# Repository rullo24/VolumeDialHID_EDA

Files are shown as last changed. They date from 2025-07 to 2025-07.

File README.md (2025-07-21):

# Custom USB HID Volume Controller – KiCad Design
KiCad schematic and PCB layout for a USB HID volume controller based on the RP2040. Features rotary encoder for volume up, volume down, and play/pause, with USB-C and onboard voltage regulation.

## Features
- RP2040 microcontroller (QFN-56 package)
- USB-C with ESD protection and fuse
- Rotary encoder with pushbutton
- Status LEDs
- SWD and UART headers for debugging

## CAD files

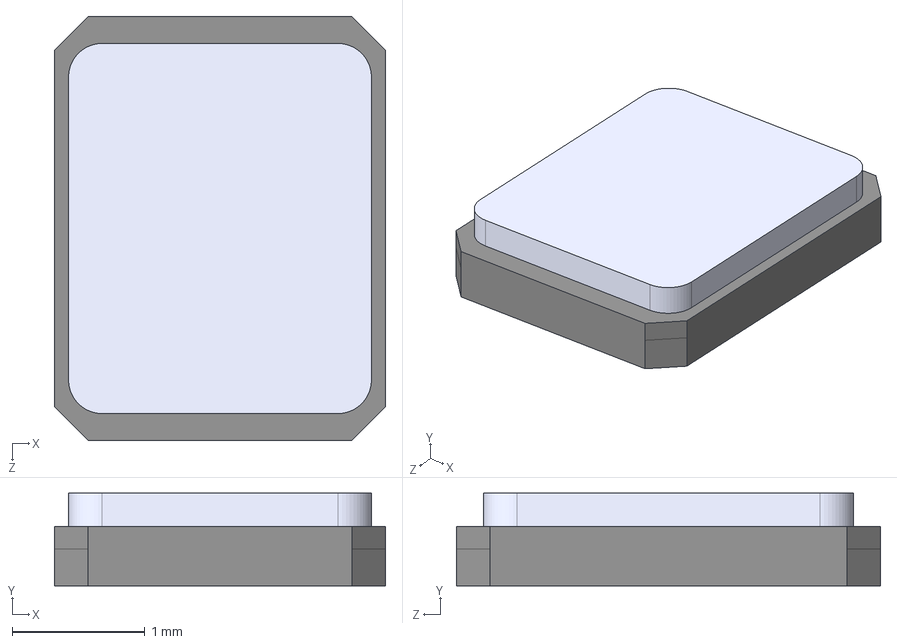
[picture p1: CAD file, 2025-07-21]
Ext_Symbols_and_Footprints/ABM8-272-T3/ABM8-272-T3.step
2.50 x 0.7 x 3.20 mm

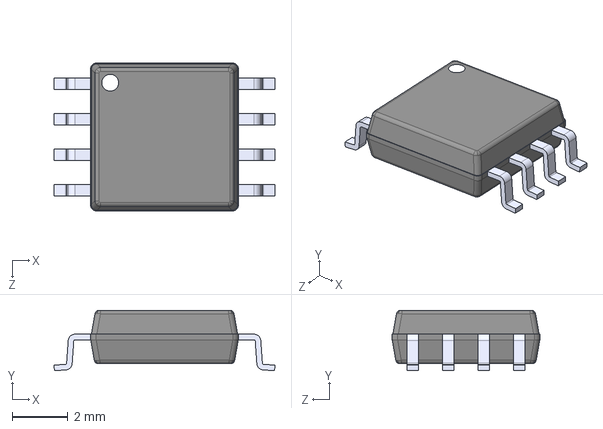
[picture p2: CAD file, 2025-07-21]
Ext_Symbols_and_Footprints/W25Q128JVSIQ/W25Q128JVSIQ.step
7.90 x 2.16 x 5.28 mm

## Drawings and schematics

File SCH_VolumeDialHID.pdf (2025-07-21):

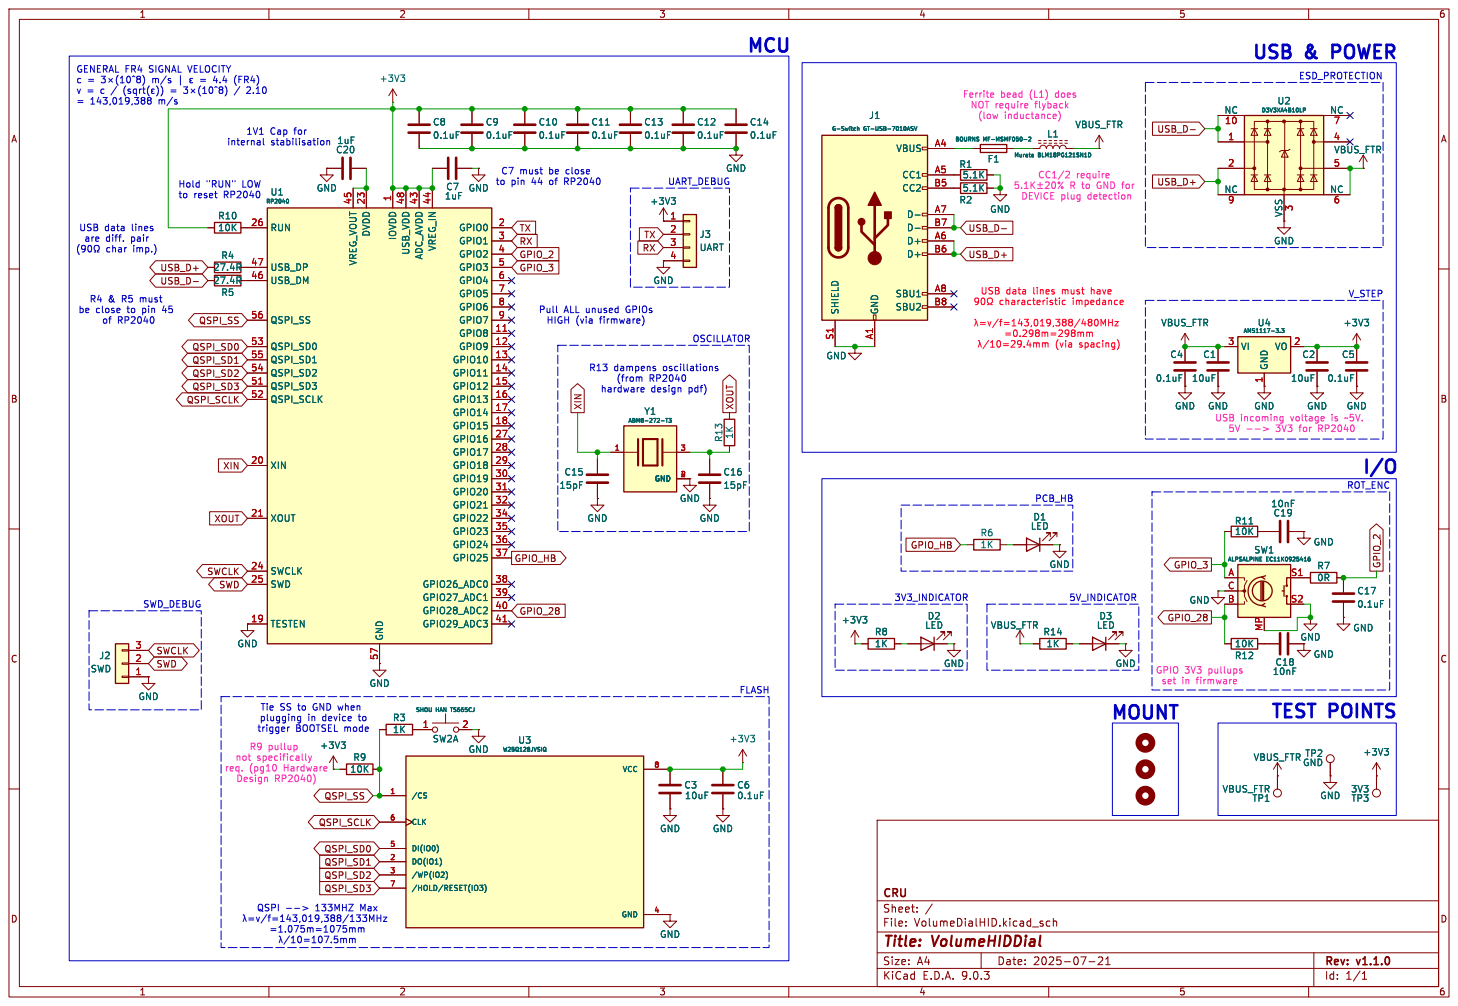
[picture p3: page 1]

þÿ5.1K±20%R to GND for DEVICE plug detection Ferrite bead (L1) does NOT require flyback

to reset RP2040 USB data lines are diff. pair

to pin 44 of RP2040 Pull ALL unused GPIOs HIGH (via firmware) Tie SS to GND when

USB data lines must have

R4 & R5 must be close to pin 45

hardware design pdf) R9 pullup

Id: 1/1 Title: VolumeHIDDial File: VolumeDialHID.kicad_sch Sheet: / CRU

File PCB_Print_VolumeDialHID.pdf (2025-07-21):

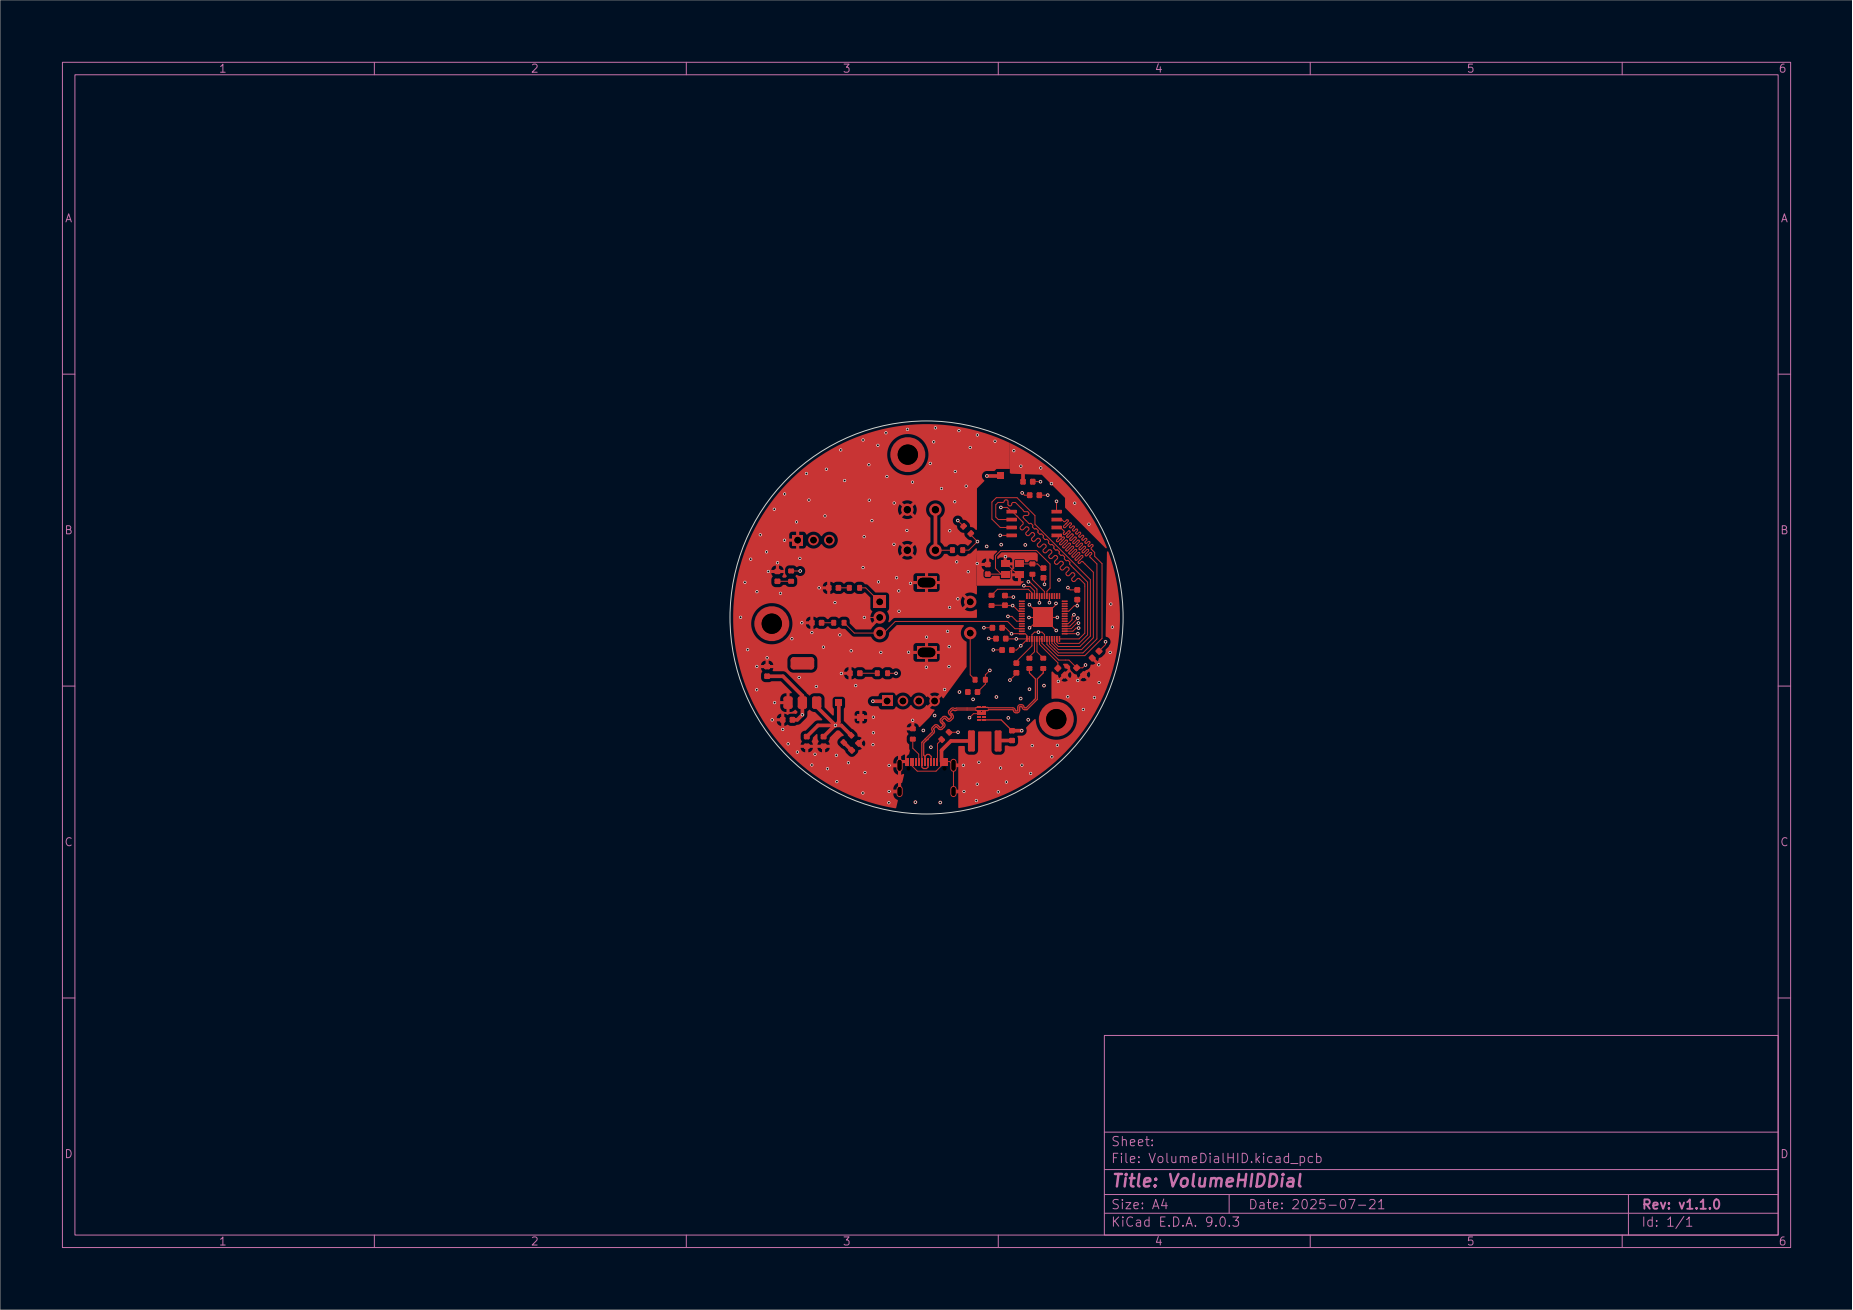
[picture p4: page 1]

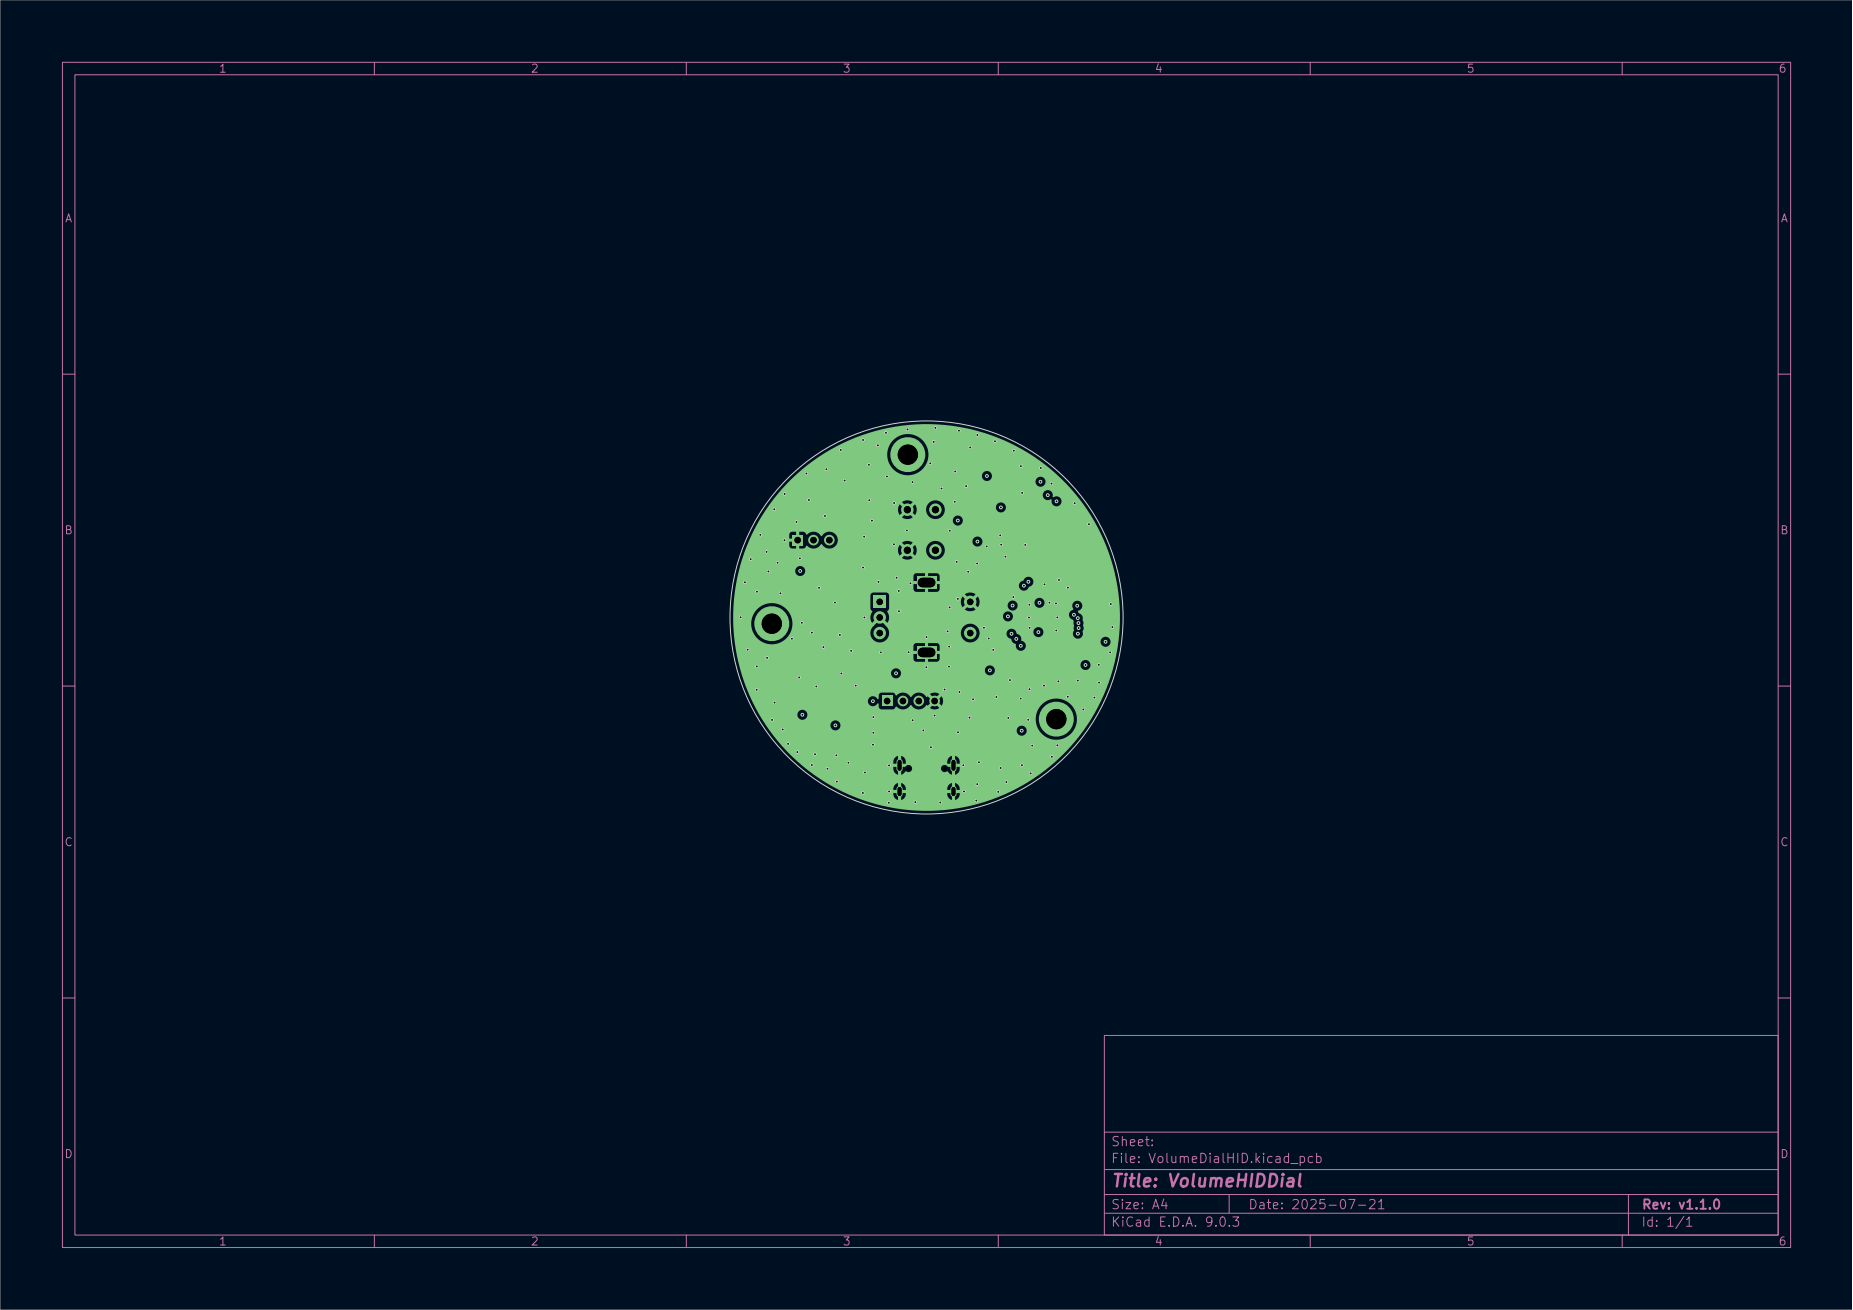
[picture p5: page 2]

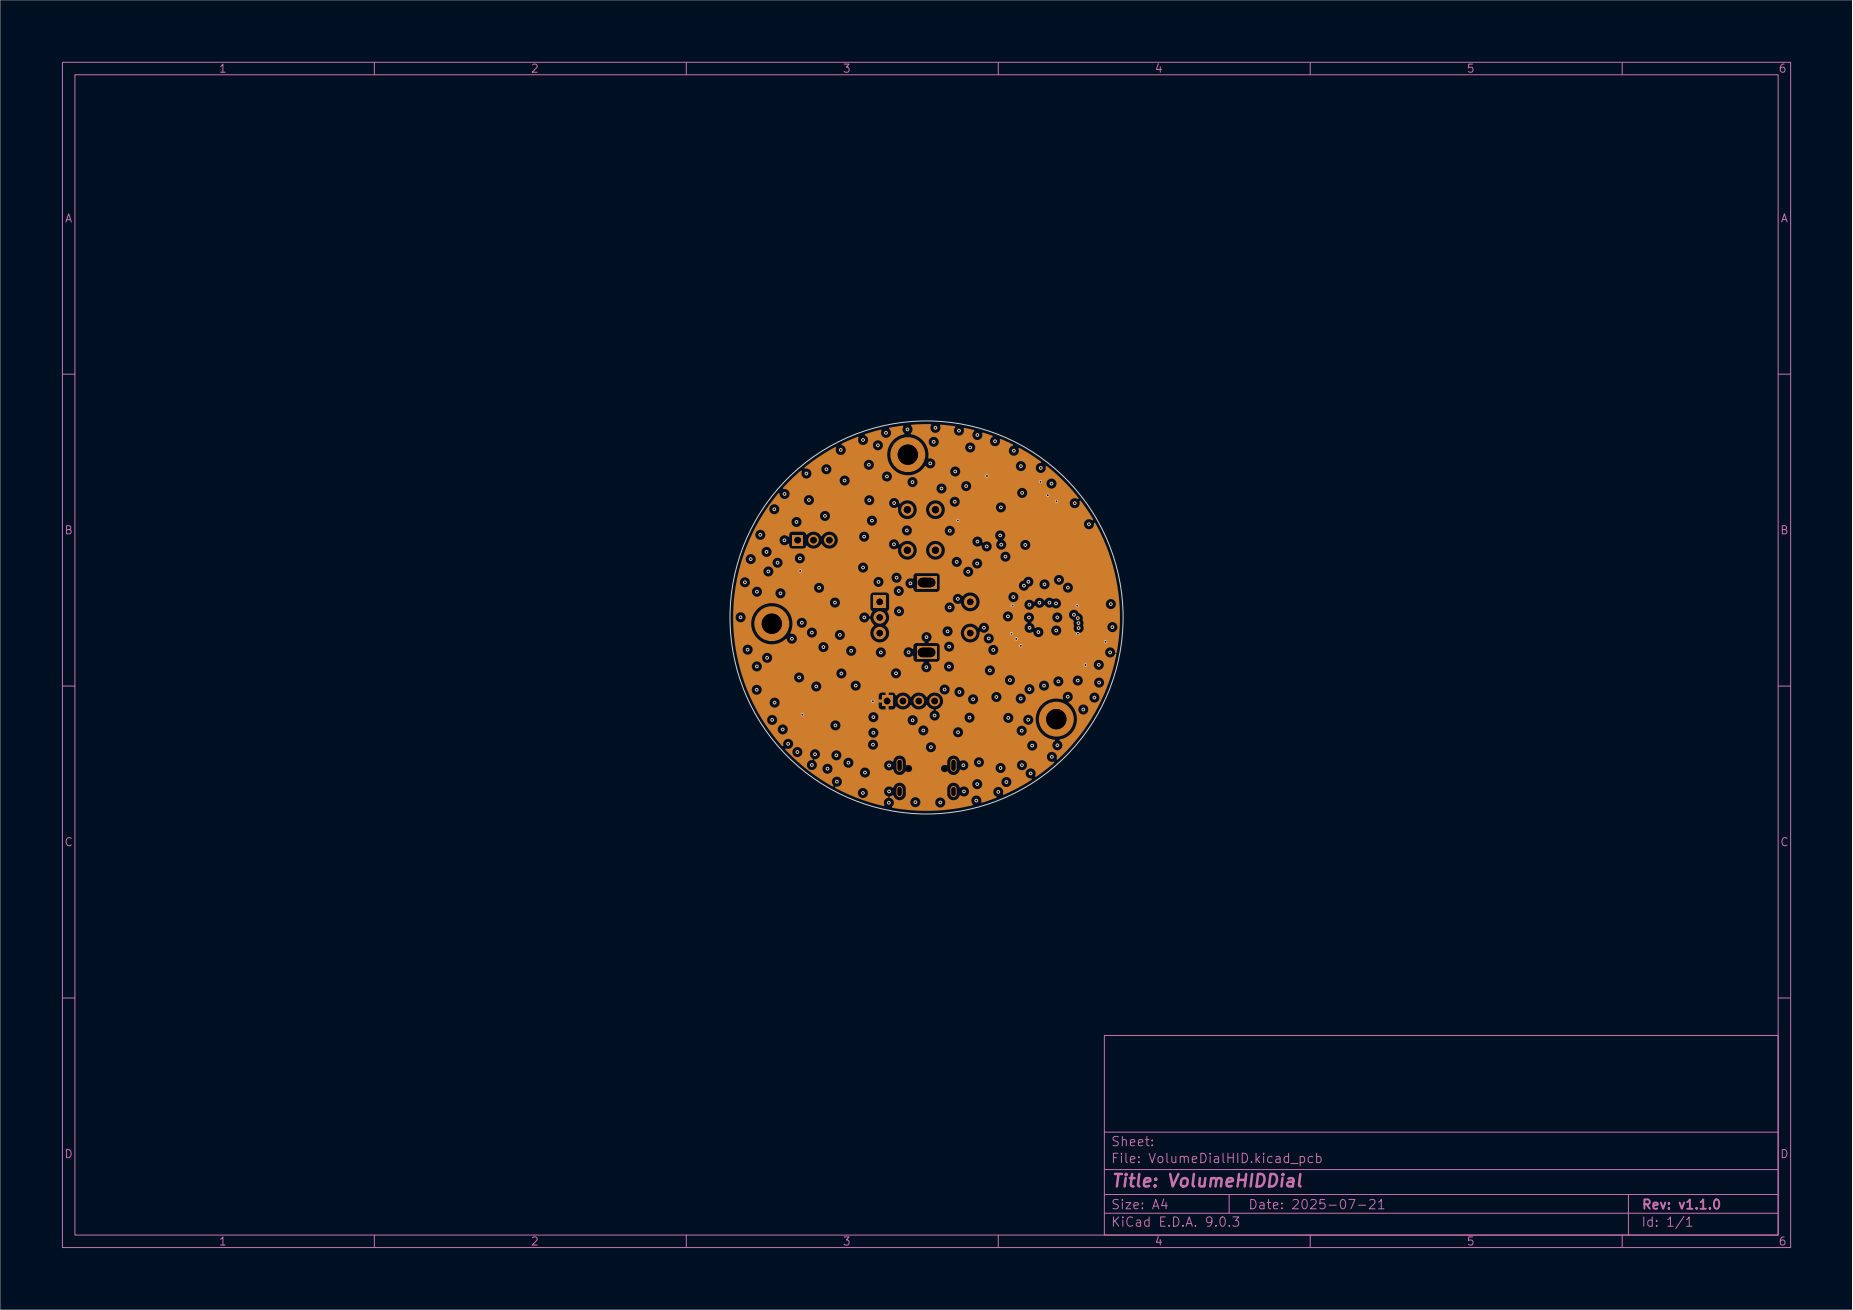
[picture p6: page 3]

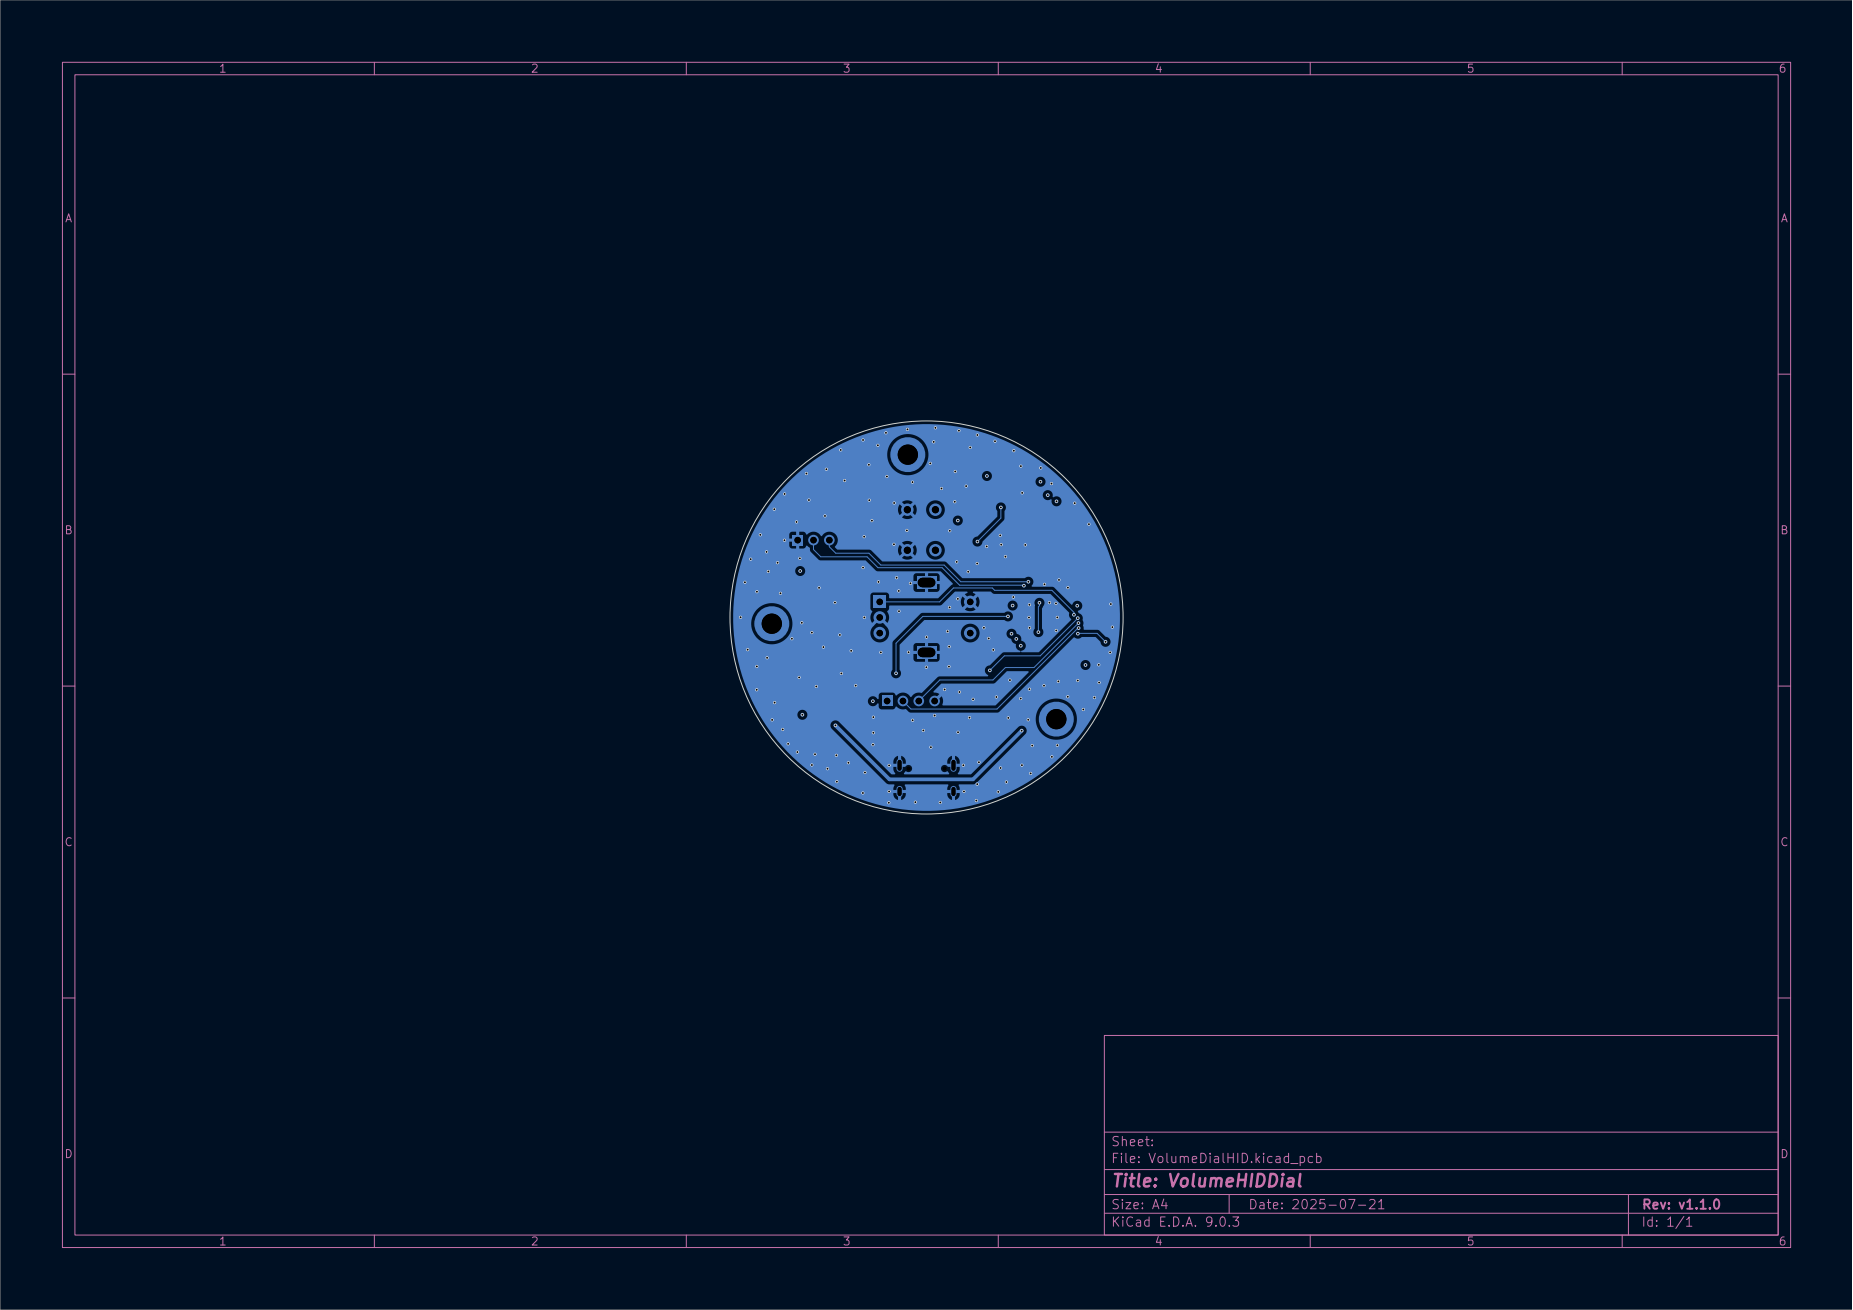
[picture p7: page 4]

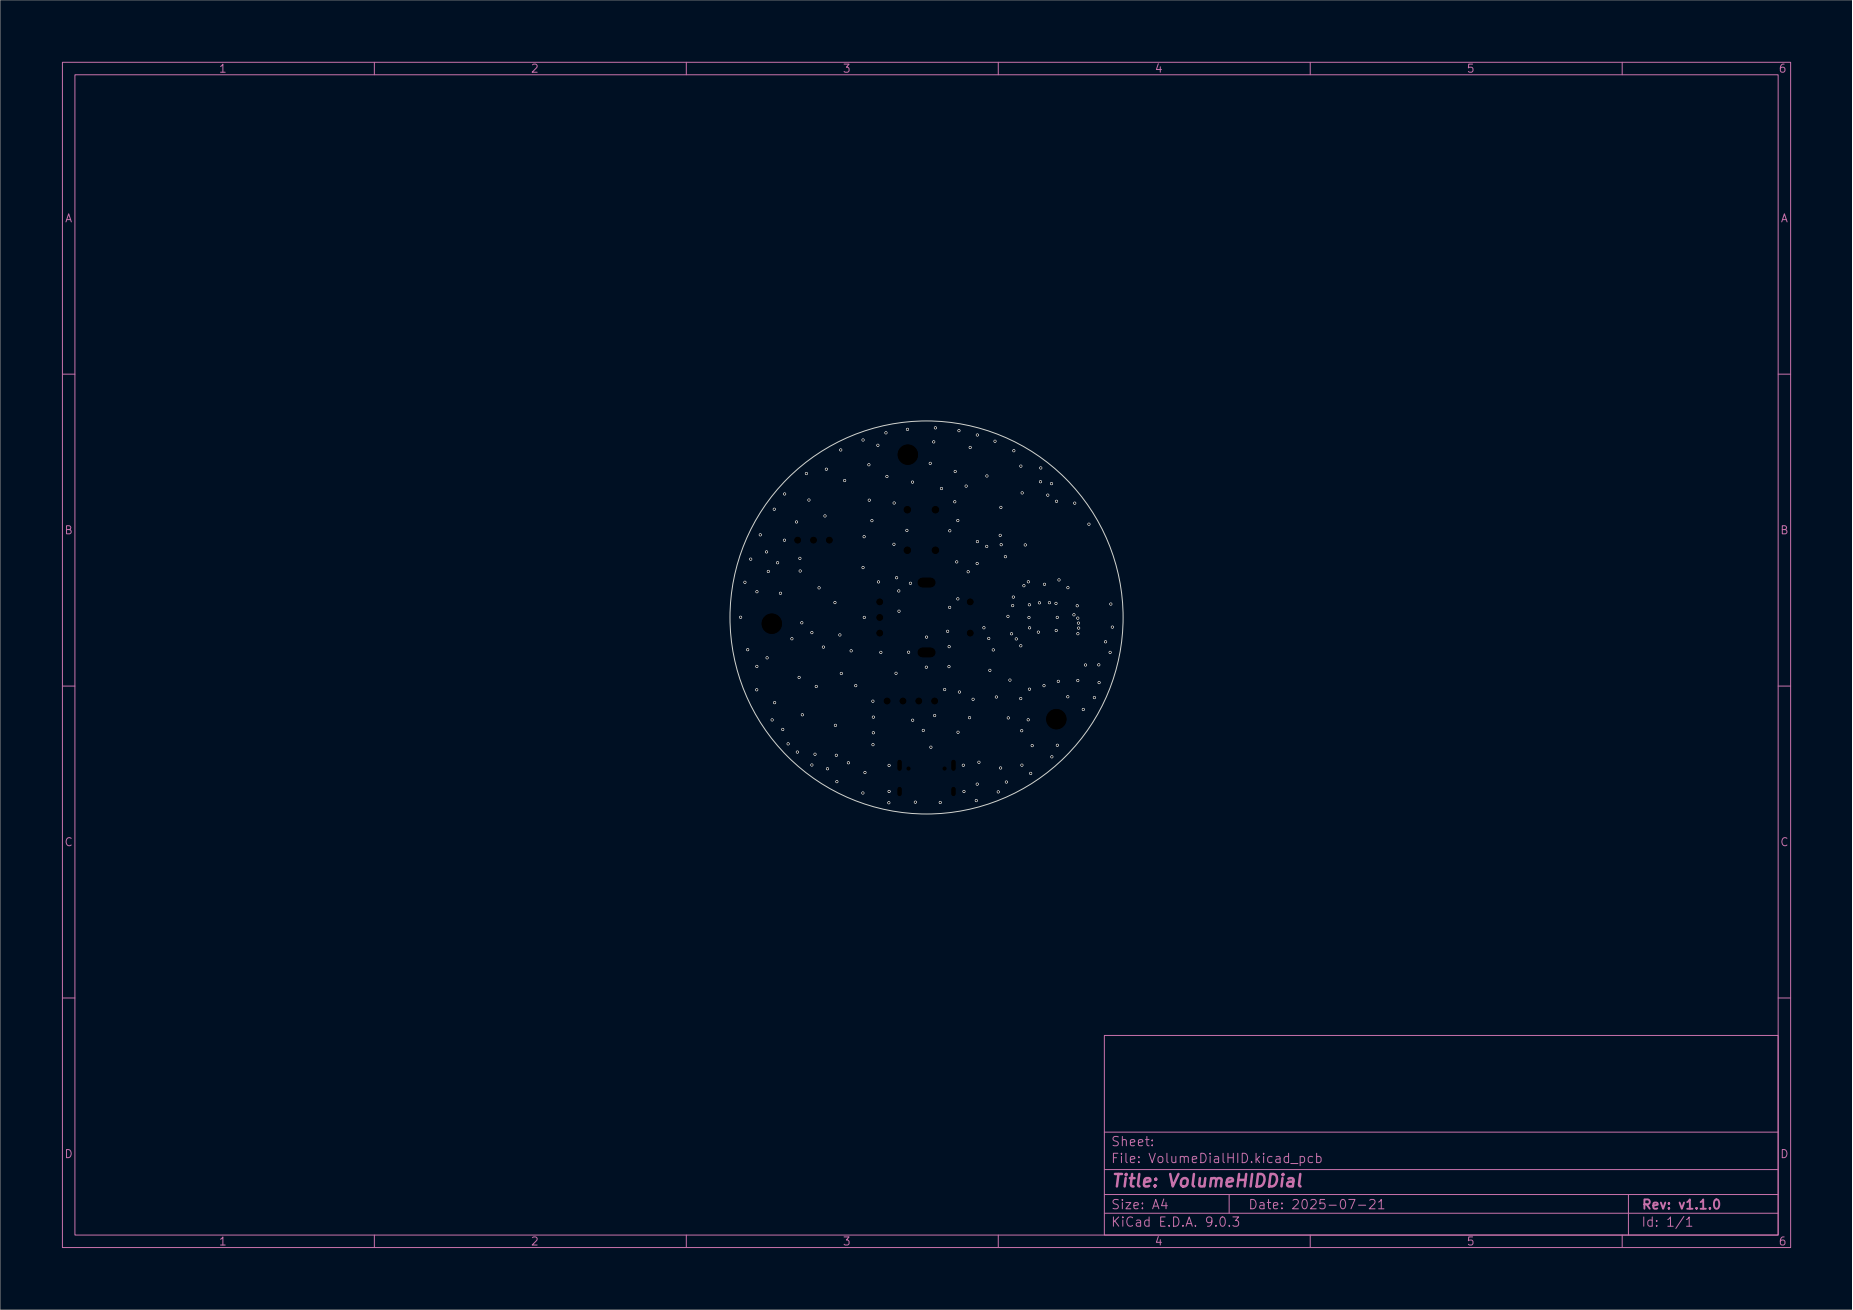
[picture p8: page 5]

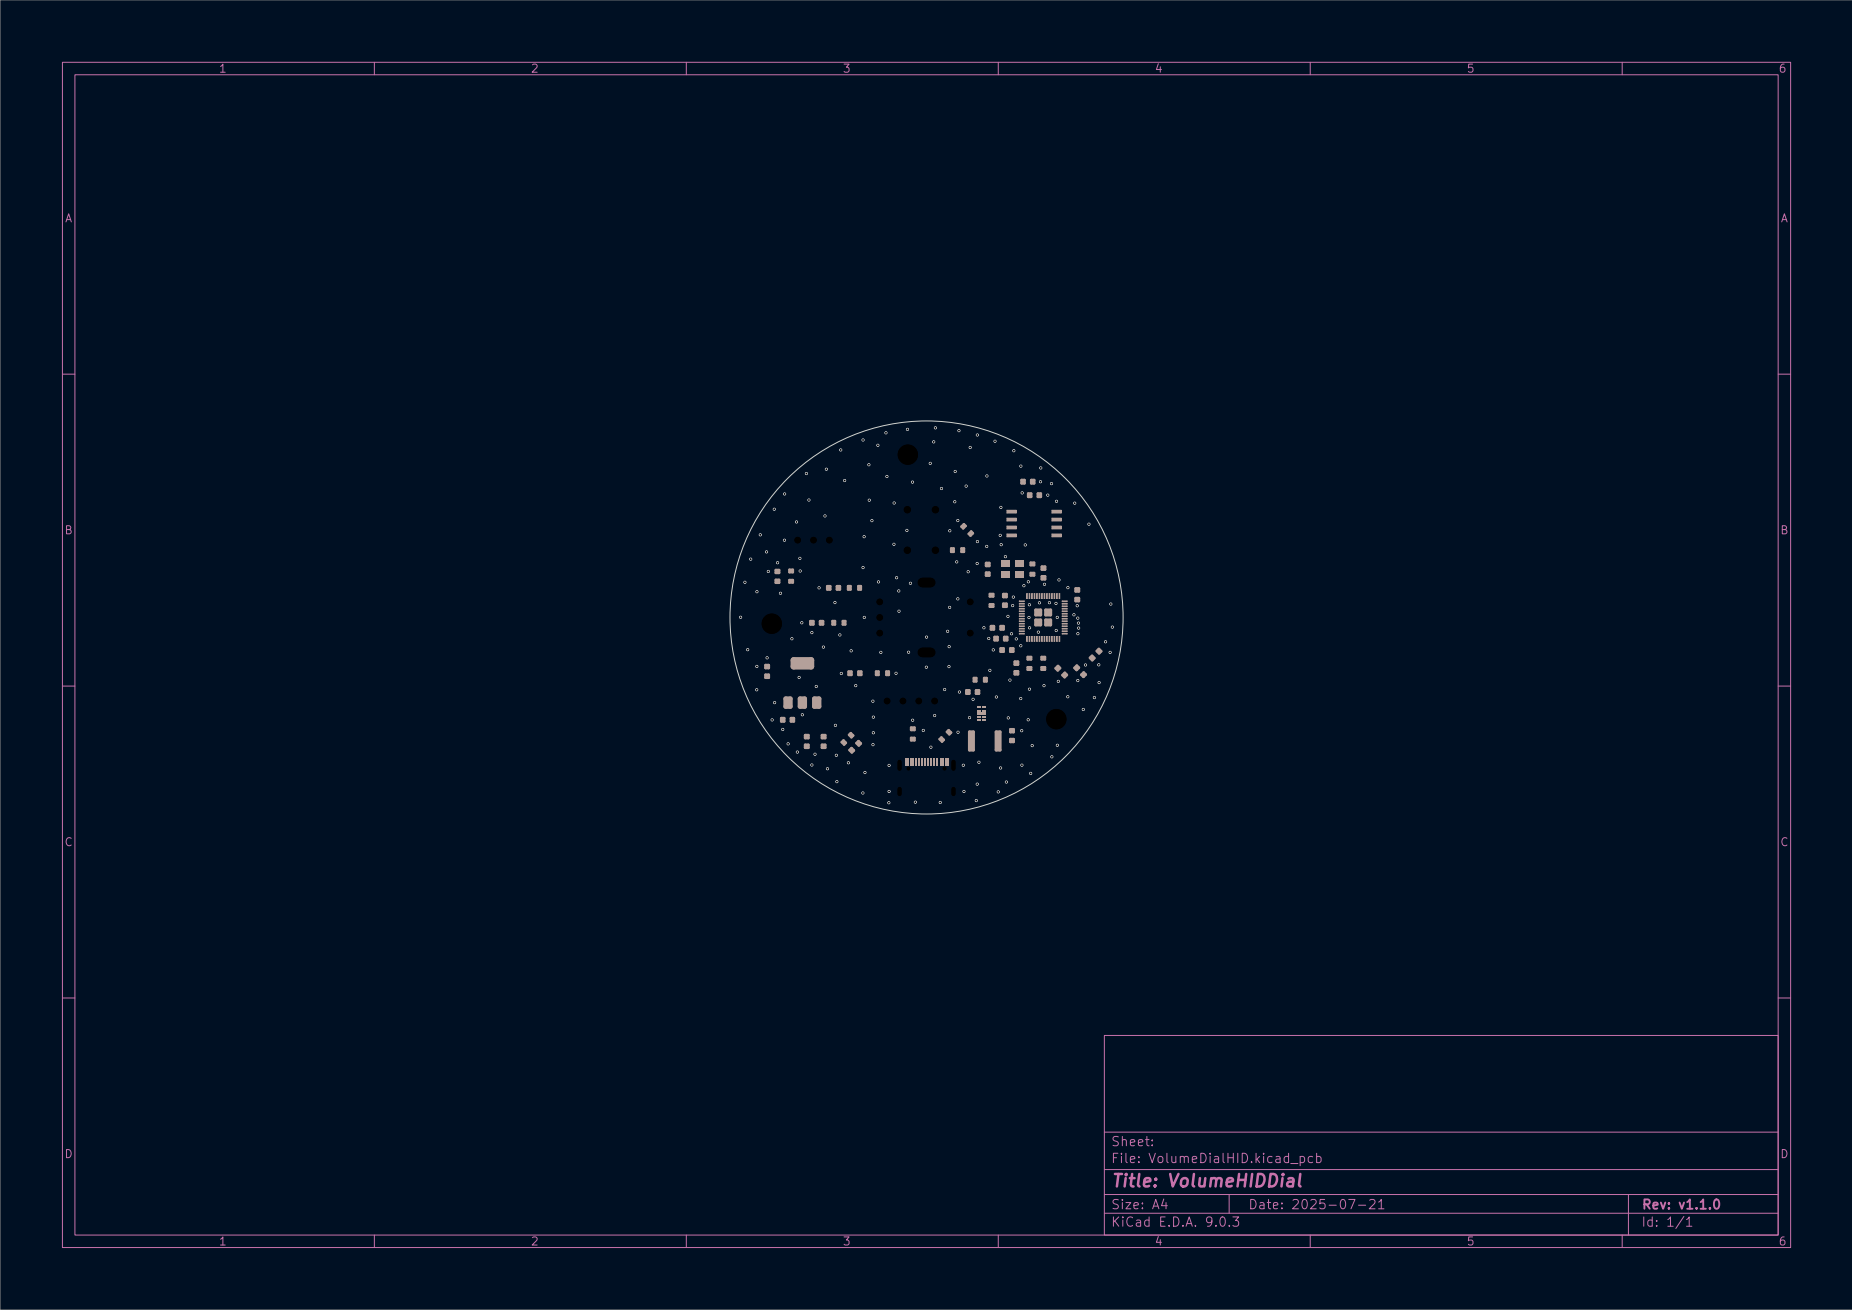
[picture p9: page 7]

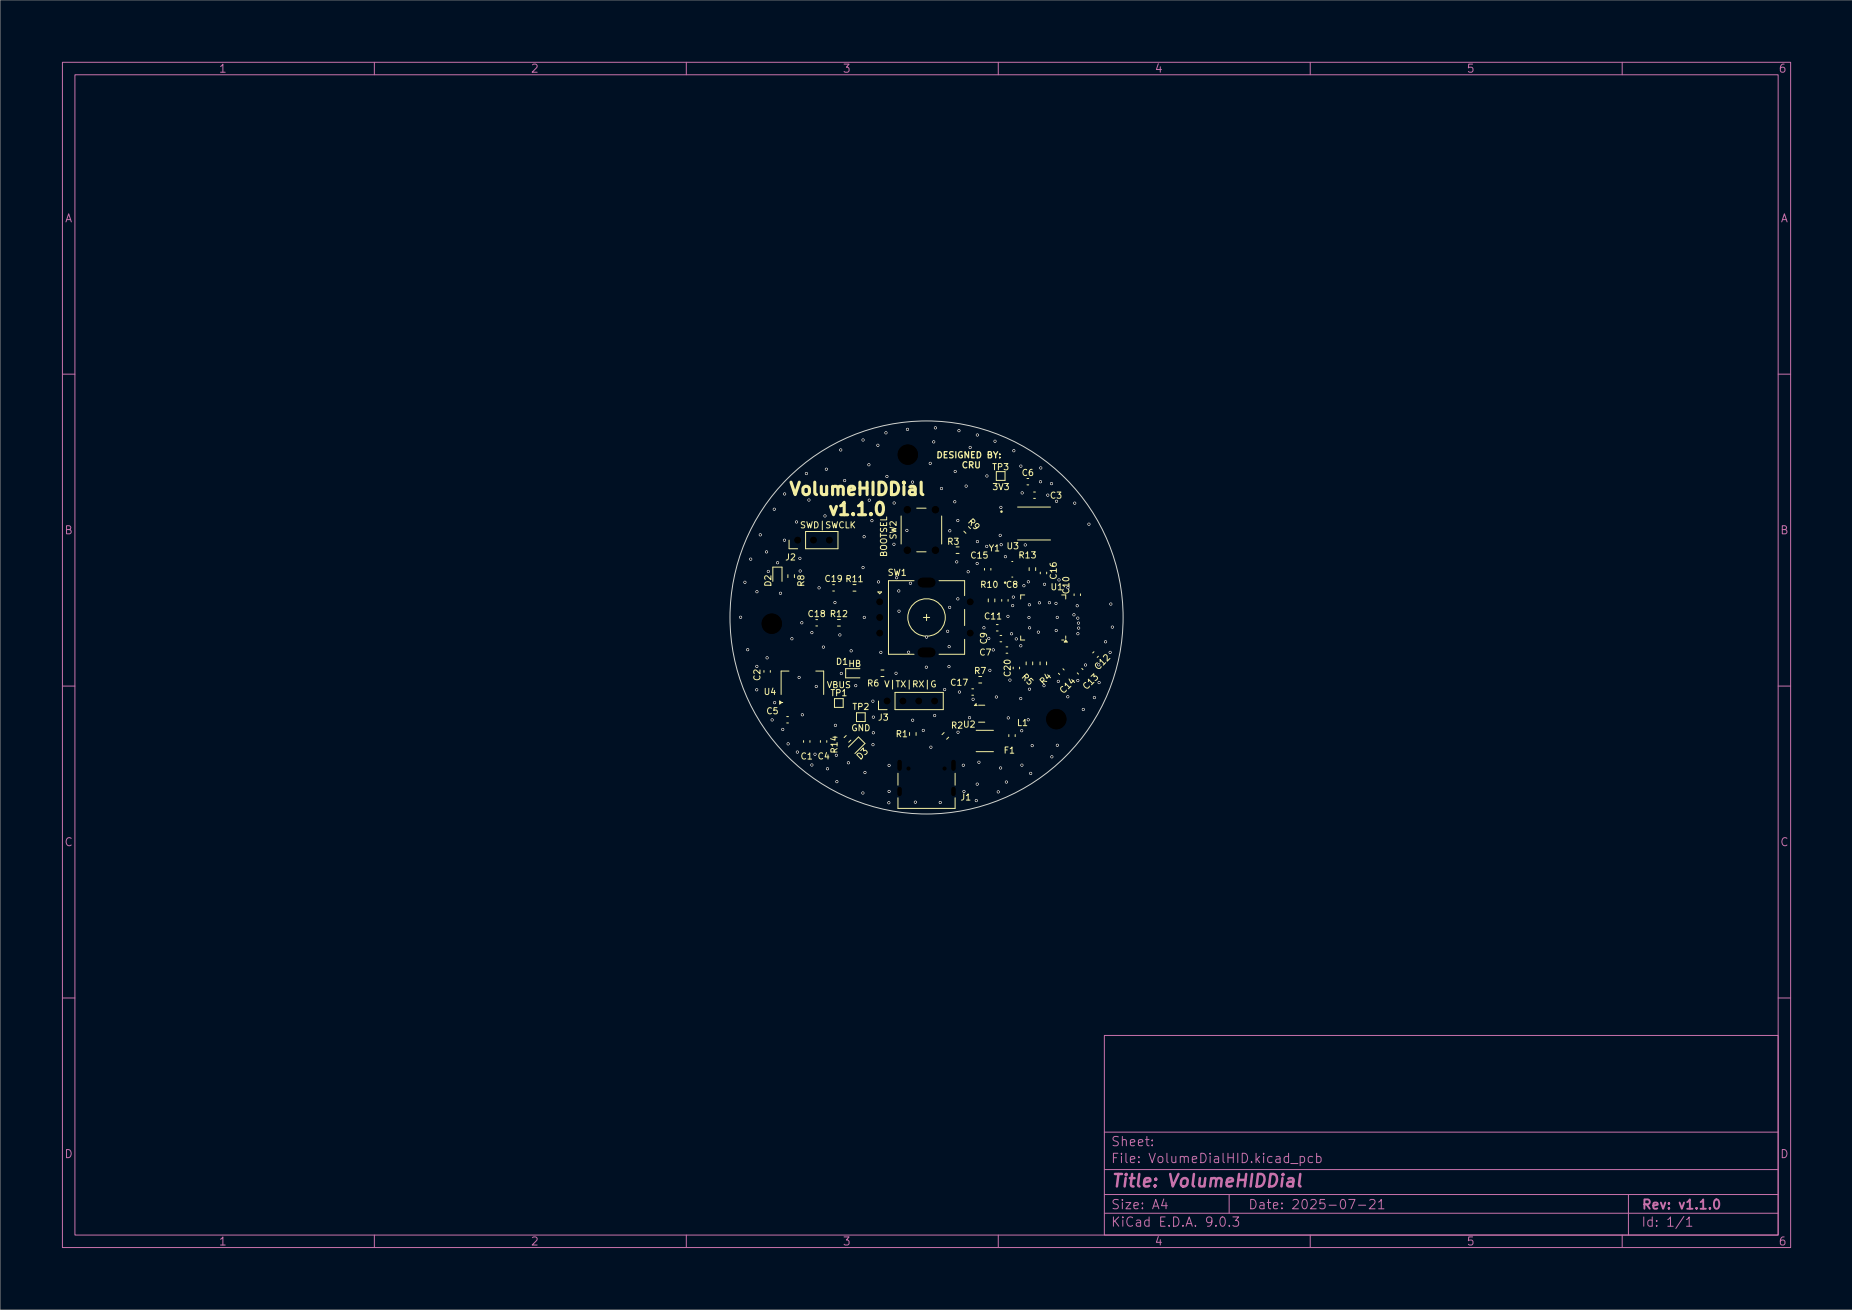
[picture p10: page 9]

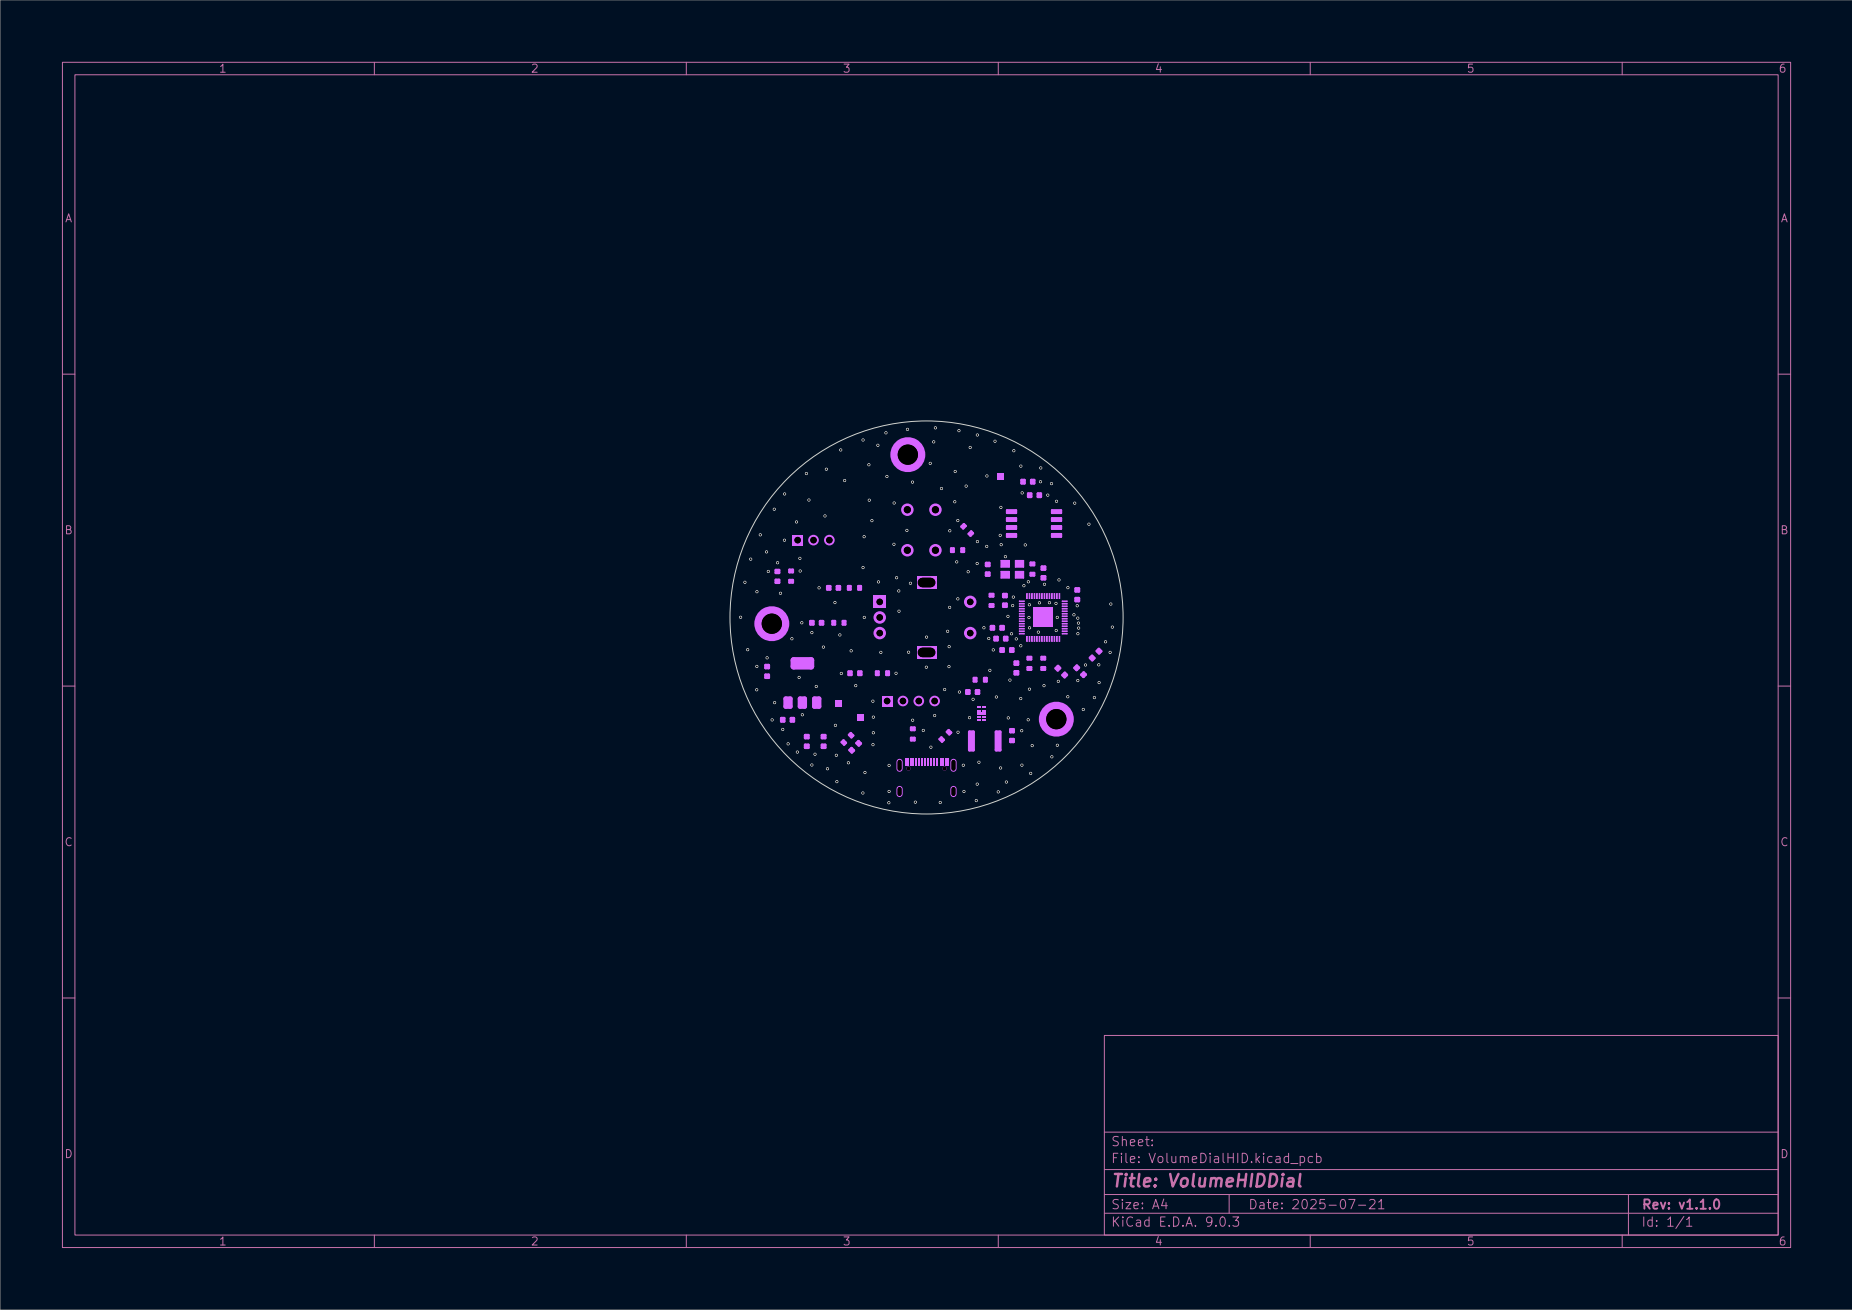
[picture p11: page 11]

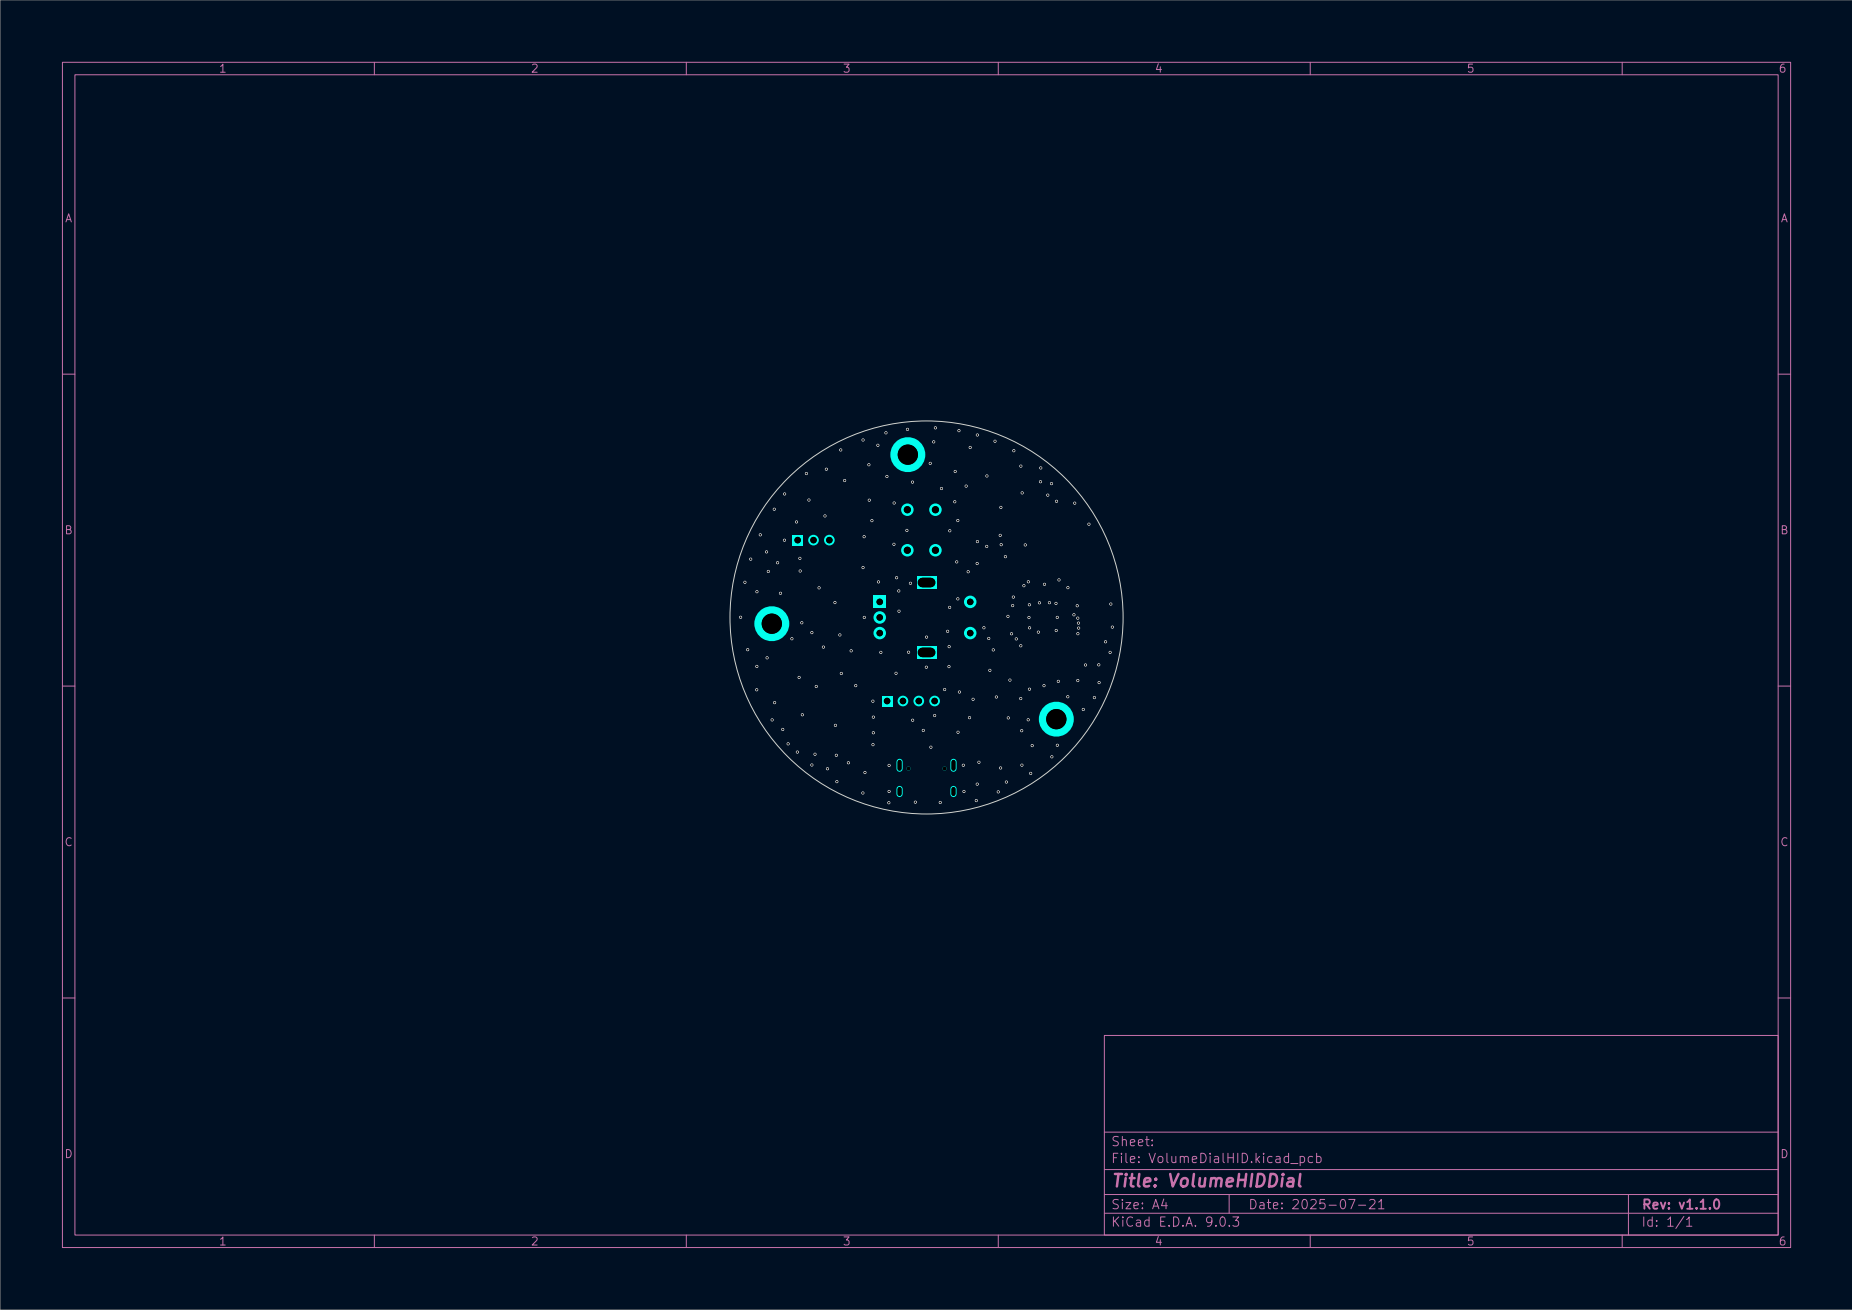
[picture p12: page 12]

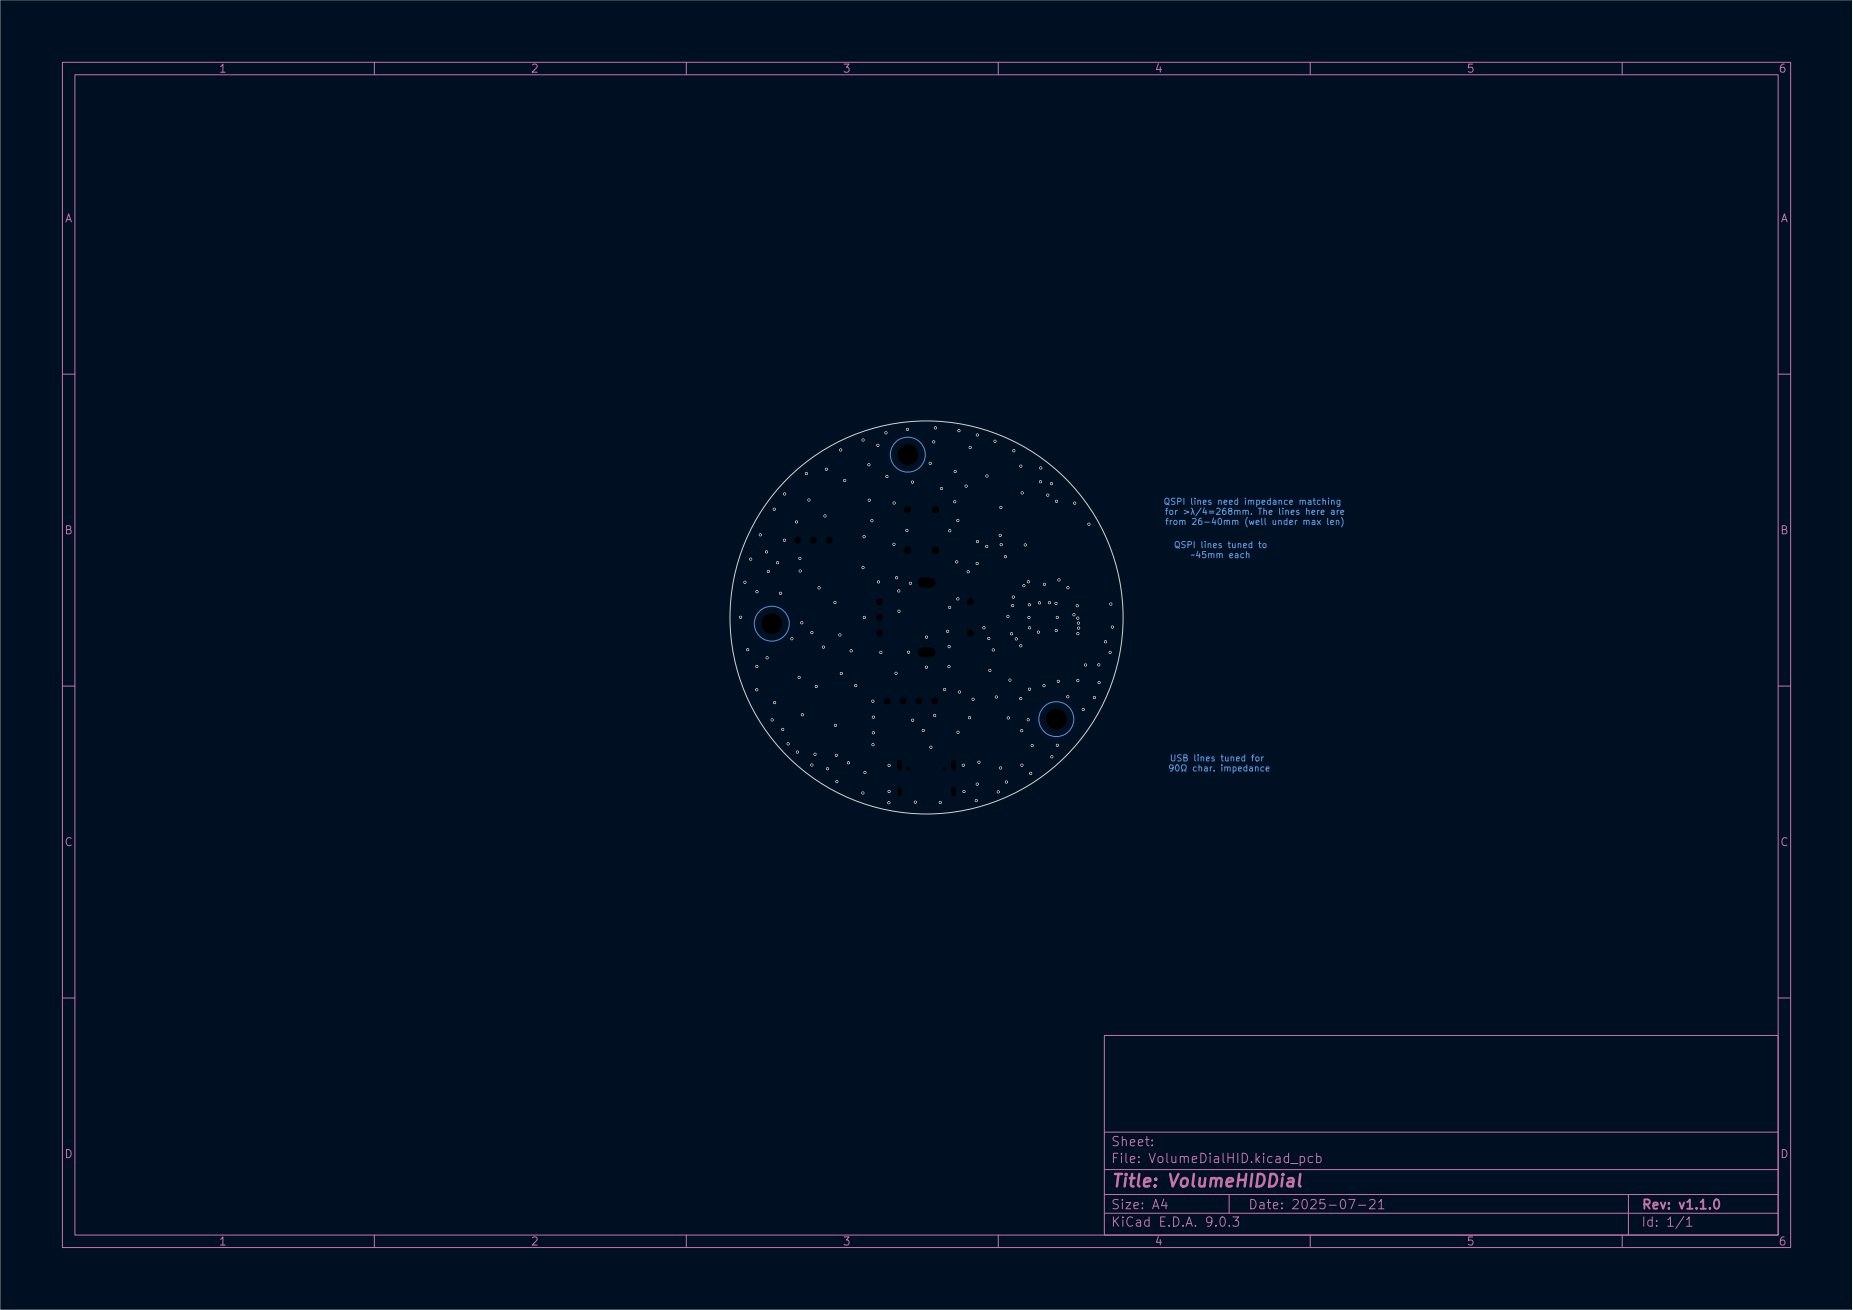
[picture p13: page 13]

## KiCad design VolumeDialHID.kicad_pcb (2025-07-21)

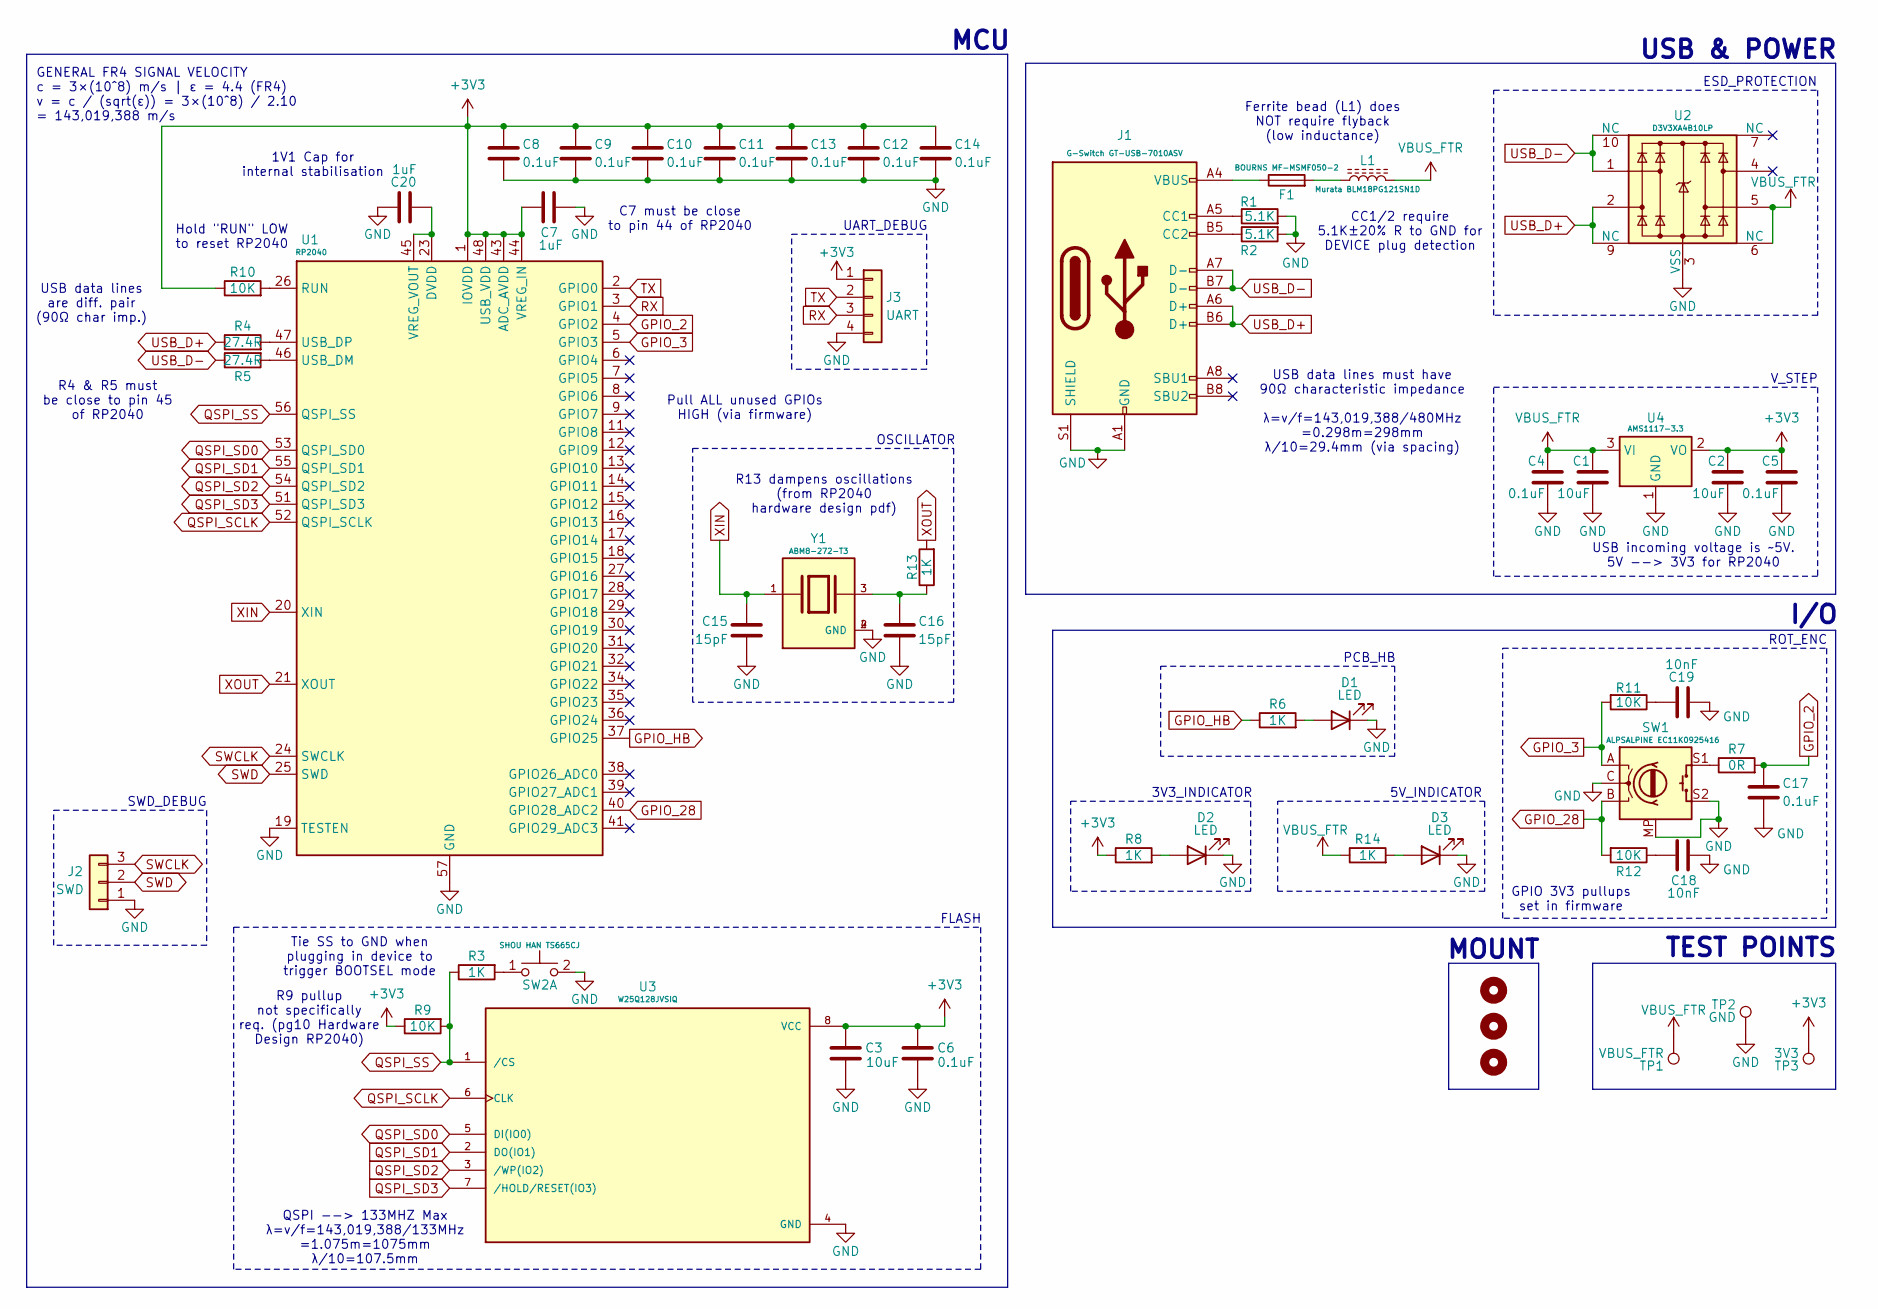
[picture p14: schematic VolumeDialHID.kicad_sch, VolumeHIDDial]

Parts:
C1, C2, C3: 10uF; C_0603_1608Metric
C4, C5, C6, C8, C9, C10, C11, C12, C13, C14, C17: 0.1uF; C_0603_1608Metric
C7, C20: 1uF; C_0603_1608Metric
C15, C16: 15pF; C_0603_1608Metric
C18, C19: 10nF; C_0603_1608Metric
D1, D2, D3: LED; LED_0603_1608Metric
F1: BOURNS MF-MSMF050-2; Fuse_1812_4532Metric
H1, H2, H3: MountingHole; MountingHole_3.2mm_M3_DIN965_Pad
J1: G-Switch GT-USB-7010ASV; USB_C_Receptacle_G-Switch_GT-USB-7010ASV
J2: SWD; PinHeader_1x03_P2.54mm_Vertical
J3: UART; PinHeader_1x04_P2.54mm_Vertical
L1: Murata BLM18PG121SN1D; Fuse_0603_1608Metric
R1, R2: 5.1K; R_0603_1608Metric
R3, R6, R8, R13, R14: 1K; R_0603_1608Metric
R4, R5: 27.4R; R_0603_1608Metric
R7: 0R; R_0603_1608Metric
R9, R10, R11, R12: 10K; R_0603_1608Metric
SW1: ALPSALPINE EC11K0925416; RotaryEncoder_Alps_EC11E-Switch_Vertical_H20mm
SW2: SHOU HAN TS665CJ; SW_PUSH_6mm
TP1: VBUS_FTR; TestPoint_Pad_1.0x1.0mm
TP2: GND; TestPoint_Pad_1.0x1.0mm
TP3: 3V3; TestPoint_Pad_1.0x1.0mm
U1: RP2040; QFN-56-1EP_7x7mm_P0.4mm_EP3.2x3.2mm
U2: D3V3XA4B10LP; Diodes_UDFN-10_1.0x2.5mm_P0.5mm
U3: W25Q128JVSIQ; SOIC127P790X216-8N; PARTREV I; DigiKey_Part_Number W25Q128JVSIQ-ND
U4: AMS1117-3.3; SOT-223
Y1: ABM8-272-T3; XTAL_ABM8-272-T3; PARTREV 07-29-20

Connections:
+3V3: C2.1, C3.2, C5.1, C6.2, C7.2, C8.1, C9.1, C10.1, C11.1, C12.1, C13.1, C14.1, J3.1, R8.1, R9.1, R10.1, TP3.1, U1.1 (IOVDD), U1.10 (IOVDD), U1.22 (IOVDD), U1.33 (IOVDD), U1.42 (IOVDD), U1.43 (ADC_AVDD), U1.44 (VREG_IN), U1.48 (USB_VDD), U1.49 (IOVDD), U3.8 (VCC), U4.2 (VO)
GND: C1.2, C2.2, C3.1, C4.2, C5.2, C6.1, C7.1, C8.2, C9.2, C10.2, C11.2, C12.2, C13.2, C14.2, C15.2, C16.2, C17.2, C18.1, C19.2, C20.1, D1.1 (K), D2.1 (K), D3.1 (K), J1.A1 (GND), J1.A12 (GND), J1.B1 (GND), J1.B12 (GND), J1.S1 (SHIELD), J2.1, J3.4, R1.2, R2.2, SW1.C, SW1.MP, SW1.S2, SW2.2 (D), TP2.1, U1.19 (TESTEN), U1.57 (GND), U2.3 (VSS), U2.8 (VSS), U3.4 (GND), U4.1 (GND), Y1.2 (GND), Y1.4 (GND)
GPIO_2: C17.1, R7.2, U1.4 (GPIO2)
GPIO_3: R11.2, SW1.A, U1.5 (GPIO3)
GPIO_28: R12.2, SW1.B, U1.40 (GPIO28_ADC2)
GPIO_HB: R6.1, U1.37 (GPIO25)
unnamed: C16.1, R13.1, Y1.3
unnamed: C18.2, R12.1
unnamed: C19.1, R11.1
unnamed: D1.2 (A), R6.2
unnamed: D2.2 (A), R8.2
unnamed: D3.2 (A), R14.2
unnamed: F1.1, J1.A4 (VBUS), J1.A9 (VBUS), J1.B4 (VBUS), J1.B9 (VBUS)
unnamed: F1.2, L1.1
unnamed: J1.A5 (CC1), R1.1
unnamed: J1.B5 (CC2), R2.1
unnamed: R7.1, SW1.S1
unnamed: R3.2, SW2.1 (C)
unnamed: R10.2, U1.26 (RUN)
unnamed: R5.2, U1.46 (USB_DM)
unnamed: R4.2, U1.47 (USB_DP)
unnamed: C20.2, U1.23 (DVDD), U1.45 (VREG_VOUT), U1.50 (DVDD)
QSPI_SCLK: U1.52 (QSPI_SCLK), U3.6 (CLK)
QSPI_SD0: U1.53 (QSPI_SD0), U3.5 (DI(IO0))
QSPI_SD1: U1.55 (QSPI_SD1), U3.2 (DO(IO1))
QSPI_SD2: U1.54 (QSPI_SD2), U3.3 (/WP(IO2))
QSPI_SD3: U1.51 (QSPI_SD3), U3.7 (/HOLD/RESET(IO3))
QSPI_SS: R3.1, R9.2, U1.56 (QSPI_SS), U3.1 (/CS)
RX: J3.3, U1.3 (GPIO1)
SWCLK: J2.3, U1.24 (SWCLK)
SWD: J2.2, U1.25 (SWD)
TX: J3.2, U1.2 (GPIO0)
USB_D+: J1.A6 (D+), J1.B6 (D+), R4.1, U2.2, U2.9 (NC)
USB_D-: J1.A7 (D-), J1.B7 (D-), R5.1, U2.1, U2.10 (NC)
VBUS_FTR: C1.1, C4.1, L1.2, R14.1, TP1.1, U2.5, U2.6 (NC), U4.3 (VI)
XIN: C15.1, U1.20 (XIN), Y1.1
XOUT: R13.2, U1.21 (XOUT)

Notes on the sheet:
V_STEP
USB & POWER
5V_INDICATOR
USB data lines are diff. pair (90Ω char imp.)
1V1 Cap for internal stabilisation
ROT_ENC
GPIO 3V3 pullups set in firmware
C7 must be close to pin 44 of RP2040
UART_DEBUG
SWD_DEBUG
GENERAL FR4 SIGNAL VELOCITY c = 3×(10^8) m/s | ε = 4.4 (FR4) v = c / (sqrt(ε)) = 3×(10^8) / 2.10 = 143,019,388 m/s
R4 & R5 must be close to pin 45 of RP2040
Pull ALL unused GPIOs HIGH (via firmware)
OSCILLATOR
PCB_HB
FLASH
USB incoming voltage is ~5V. 5V --> 3V3 for RP2040
Tie SS to GND when plugging in device to trigger BOOTSEL mode
USB data lines must have 90Ω characteristic impedance λ=v/f=143,019,388/480MHz =0.298m=298mm λ/10=29.4mm (via spacing)
I/O
R13 dampens oscillations (from RP2040 hardware design pdf)
CC1/2 require 5.1K±20% R to GND for DEVICE plug detection
ESD_PROTECTION
MCU
3V3_INDICATOR
R9 pullup not specifically req. (pg10 Hardware Design RP2040)
MOUNT
Ferrite bead (L1) does NOT require flyback (low inductance)
TEST POINTS
Hold "RUN" LOW to reset RP2040
QSPI --> 133MHZ Max λ=v/f=143,019,388/133MHz =1.075m=1075mm λ/10=107.5mm

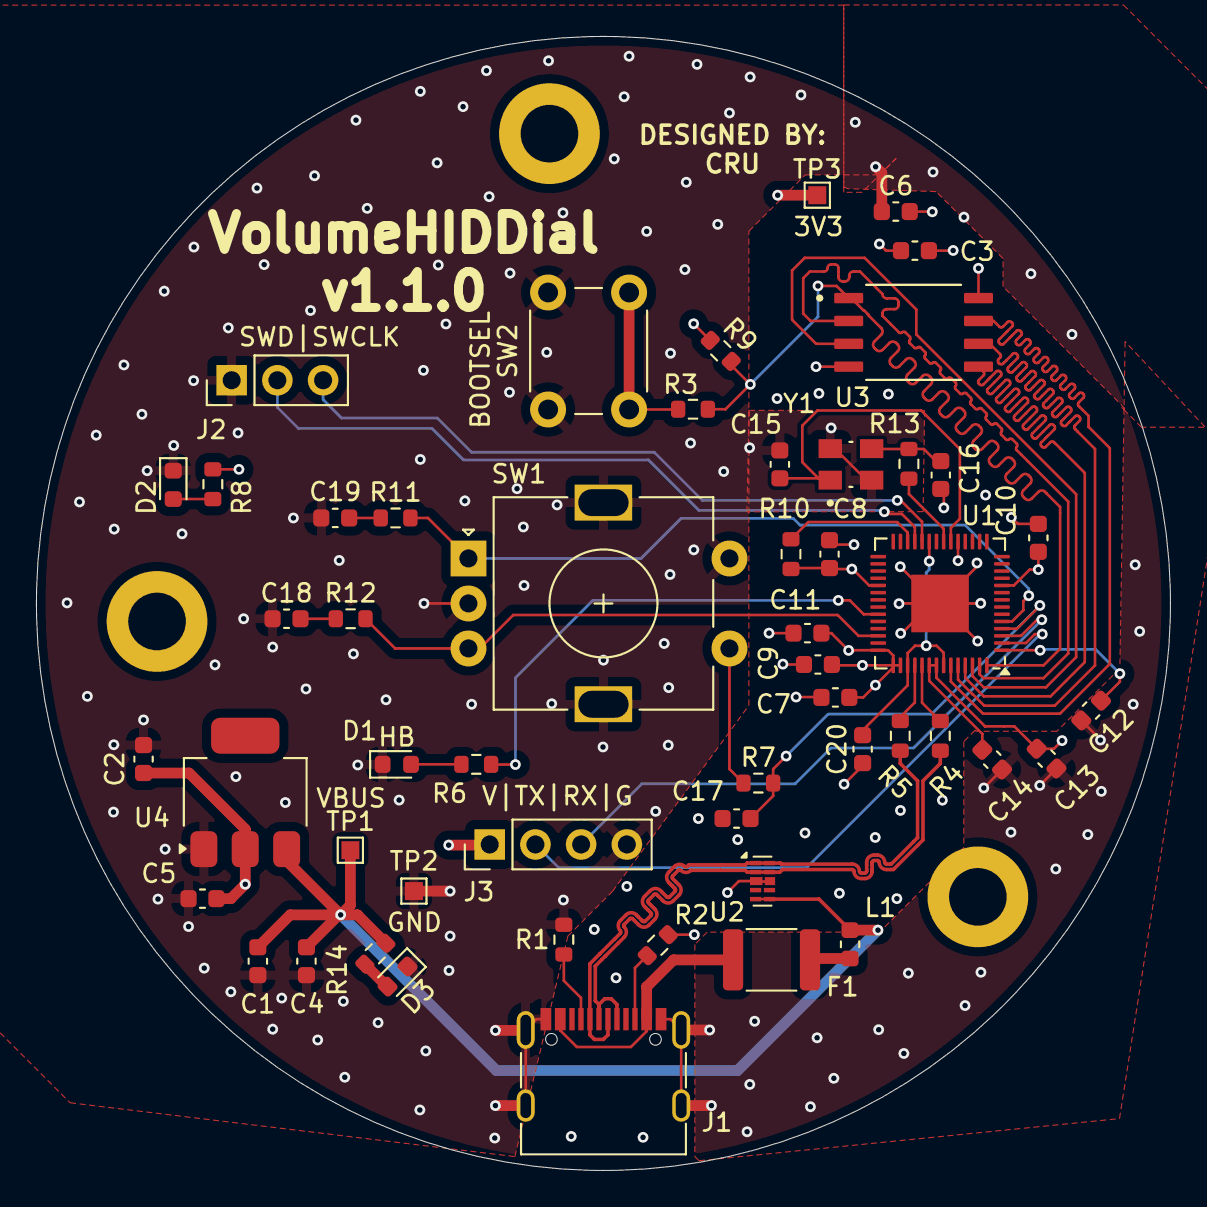
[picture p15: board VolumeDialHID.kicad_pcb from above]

Board: 4 copper layers, 63.0 x 63.0 mm, 55 parts (0 on the bottom side), 37 nets.
